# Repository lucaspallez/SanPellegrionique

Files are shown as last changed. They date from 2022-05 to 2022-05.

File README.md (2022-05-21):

# SanPellegrionique
Flight Avionics PCB for a Water Rocket  
This project was done in the scope of a project for the EPFL ENG-510 Space Propulsion Class

Embedded Software for this board available here: https://github.com/lucaspallez/COTS_SanPellegrinOS   
Compatible Ground Station PCB: https://github.com/lucaspallez/GRUND

## Features
- Computation: Arduino Nano v3
- Telemetry: RFM95W LoRa Module (with SMA connector)
- IMU: MPU 6050 Breakout
- Barometer: BMP 280 Breakout
- Power Output: 1 MOSFET Pyro output up to 3.6A
- Servo Output: 1 PWM output
- Power Inputs: 1x 2s LiPo Battery connector
- Arming: 1x Main external arm switch
- Status Indicators: 5x User programmable LEDs
- Battery voltage readings

## Documentation

Designed with KiCAD 6.0

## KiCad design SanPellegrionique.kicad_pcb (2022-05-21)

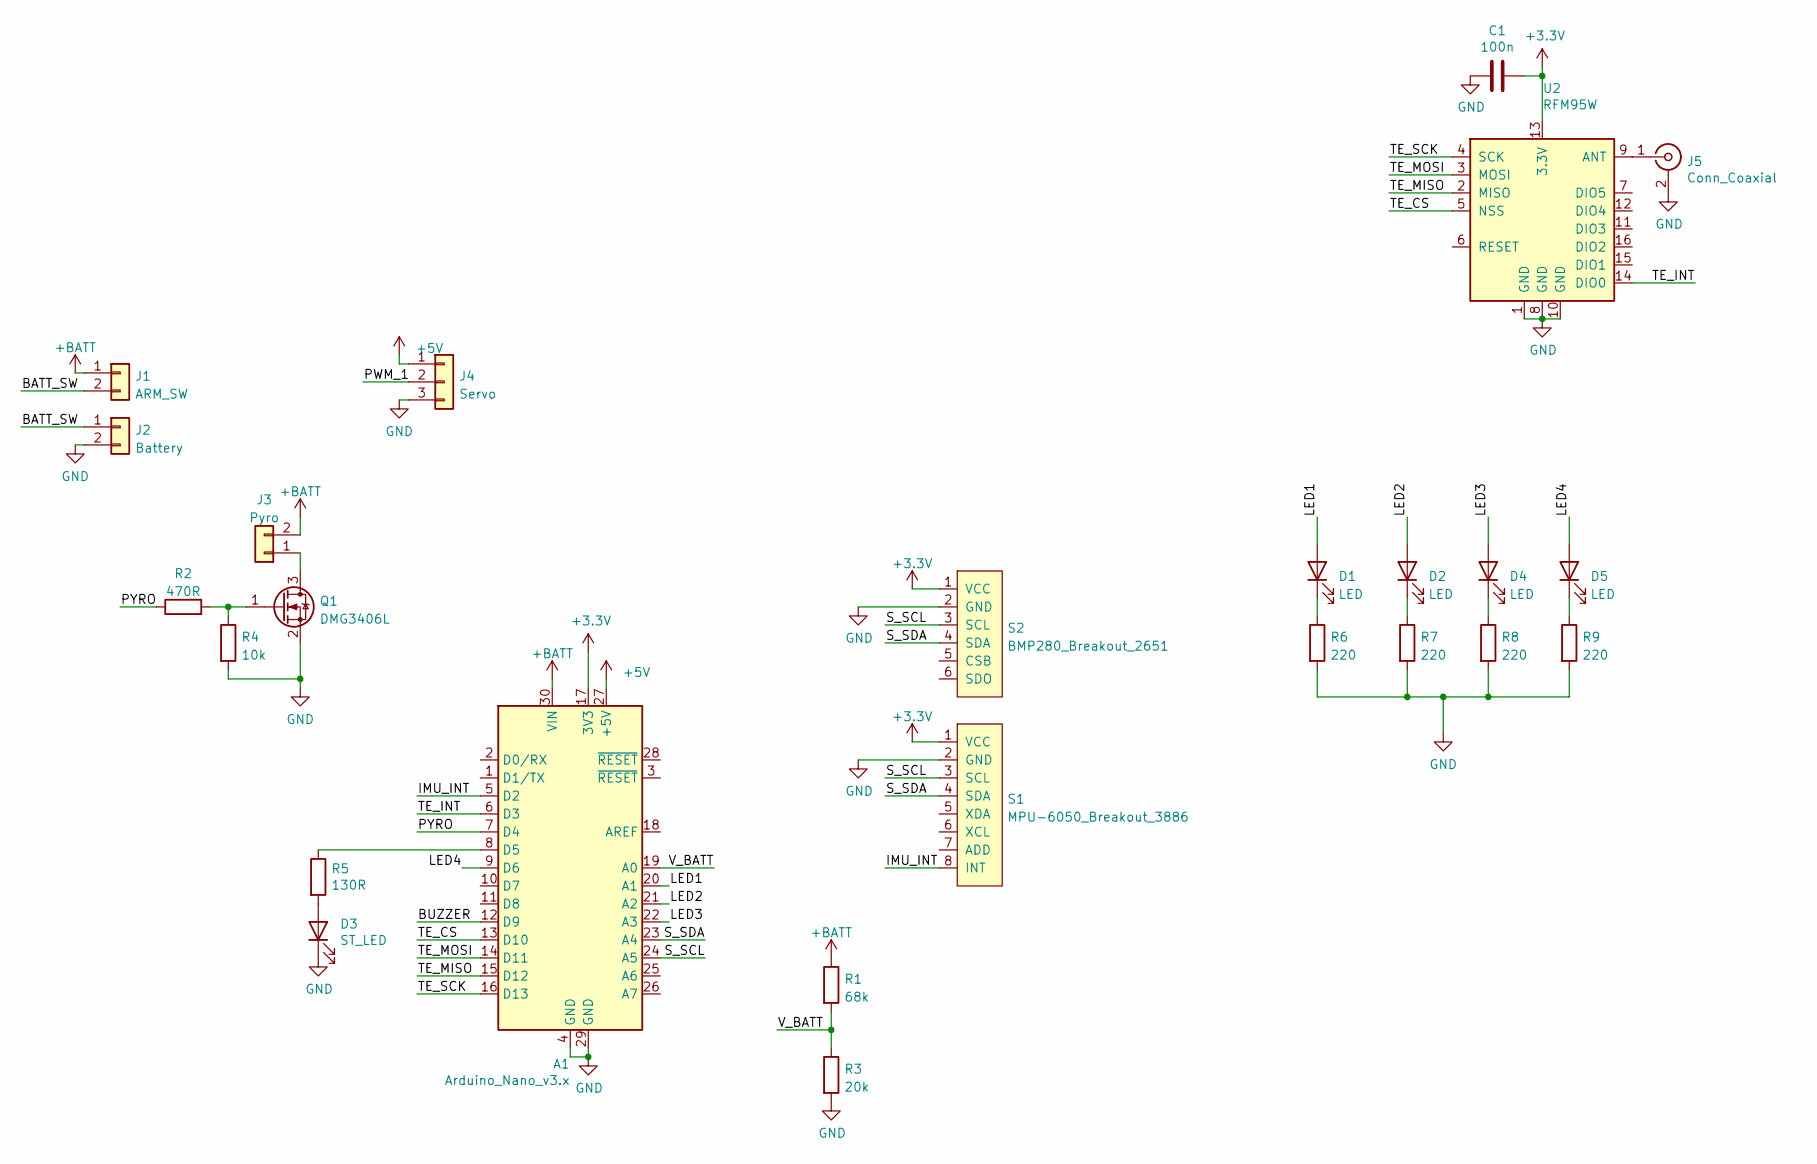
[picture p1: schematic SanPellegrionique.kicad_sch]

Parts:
A1: Arduino_Nano_v3.x; Arduino_Nano
C1: 100n; C_0805_2012Metric
D1, D2, D4, D5: LED; LED_0603_1608Metric_Pad1.05x0.95mm_HandSolder
D3: ST_LED; LED_0603_1608Metric
J1: ARM_SW; JST_PH_S2B-PH-K_1x02_P2.00mm_Horizontal
J2: Battery; JST_PH_S2B-PH-K_1x02_P2.00mm_Horizontal
J3: Pyro; JST_PH_S2B-PH-K_1x02_P2.00mm_Horizontal
J4: Servo; JST_PH_S3B-PH-K_1x03_P2.00mm_Horizontal
J5: Conn_Coaxial; SMA_Wurth_60312002114503_Vertical
Q1: DMG3406L; SOT-23
R1: 68k; R_0805_2012Metric_Pad1.20x1.40mm_HandSolder
R2: 470R; R_0805_2012Metric_Pad1.20x1.40mm_HandSolder
R3: 20k; R_0805_2012Metric_Pad1.20x1.40mm_HandSolder
R4: 10k; R_0805_2012Metric_Pad1.20x1.40mm_HandSolder
R5: 130R; R_0805_2012Metric_Pad1.20x1.40mm_HandSolder
R6, R7, R8, R9: 220; R_0805_2012Metric_Pad1.20x1.40mm_HandSolder
S1: MPU-6050_Breakout_3886; MPU_6050_Breakout
S2: BMP280_Breakout_2651; BMP_280_Breakout
U2: RFM95W; HOPERF_RFM9XW_SMD

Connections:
+3V3: A1.17 (3V3), C1.1, S1.1 (VCC), S2.1 (VCC), U2.13 (3.3V)
+5V: A1.27 (+5V), J4.1
+BATT: A1.30 (VIN), J1.1, J3.2, R1.1
/BATT_SW: J1.2, J2.1
/BUZZER: A1.12 (D9)
/IMU_INT: A1.5 (D2), S1.8 (INT)
/LED1: A1.20 (A1), D1.2 (A)
/LED2: A1.21 (A2), D2.2 (A)
/LED3: A1.22 (A3), D4.2 (A)
/LED4: A1.9 (D6), D5.2 (A)
/PWM_1: J4.2
/PYRO: A1.7 (D4), R2.1
/S_SCL: A1.24 (A5), S1.3 (SCL), S2.3 (SCL)
/S_SDA: A1.23 (A4), S1.4 (SDA), S2.4 (SDA)
/TE_CS: A1.13 (D10), U2.5 (NSS)
/TE_INT: A1.6 (D3), U2.14 (DIO0)
/TE_MISO: A1.15 (D12), U2.2 (MISO)
/TE_MOSI: A1.14 (D11), U2.3 (MOSI)
/TE_SCK: A1.16 (D13), U2.4 (SCK)
/V_BATT: A1.19 (A0), R1.2, R3.1
GND: A1.4 (GND), A1.29 (GND), C1.2, D3.1 (K), J2.2, J4.3, J5.2 (Ext), Q1.2 (S), R3.2, R4.2, R6.2, R7.2, R8.2, R9.2, S1.2 (GND), S2.2 (GND), U2.1 (GND), U2.8 (GND), U2.10 (GND)
unnamed: A1.8 (D5), R5.1
unnamed: D1.1 (K), R6.1
unnamed: D2.1 (K), R7.1
unnamed: D3.2 (A), R5.2
unnamed: D4.1 (K), R8.1
unnamed: D5.1 (K), R9.1
unnamed: J3.1, Q1.3 (D)
unnamed: J5.1 (In), U2.9 (ANT)
unnamed: Q1.1 (G), R2.2, R4.1

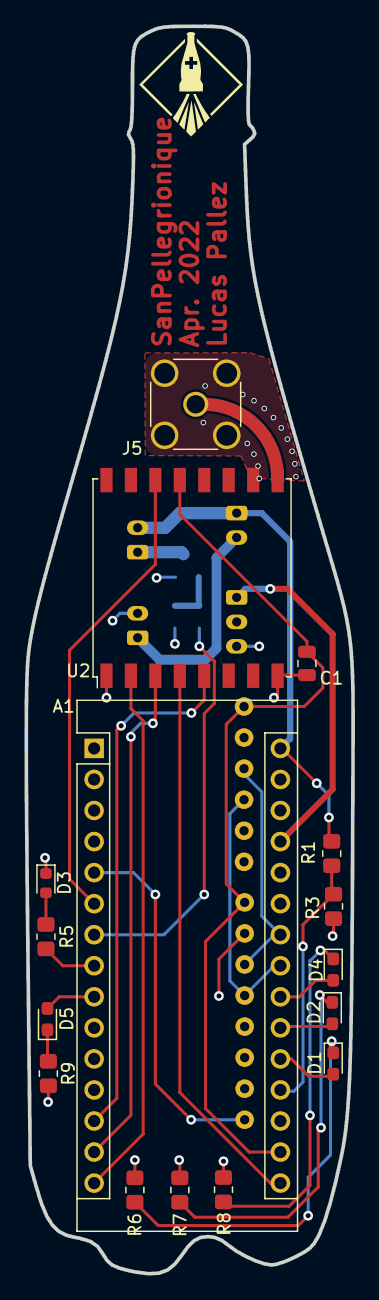
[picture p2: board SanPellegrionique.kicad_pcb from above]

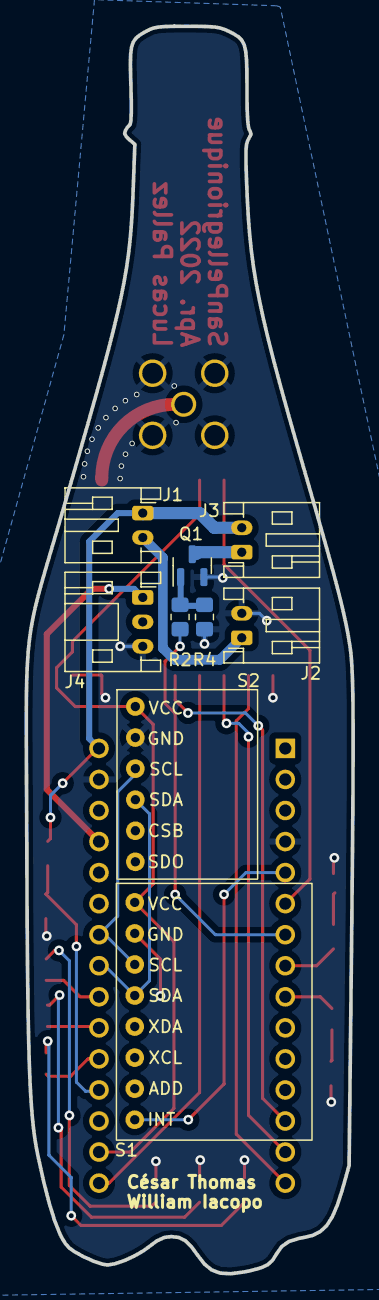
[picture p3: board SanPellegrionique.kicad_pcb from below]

Board: 2 copper layers, 26.7 x 102.0 mm, 25 parts (9 on the bottom side), 28 nets.
